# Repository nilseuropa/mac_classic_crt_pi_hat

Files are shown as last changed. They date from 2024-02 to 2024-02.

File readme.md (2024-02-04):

## Classic Mac CRT driver HAT for Raspberry Pi4

:warning: **Proof of concept running PoP on minivmac:**
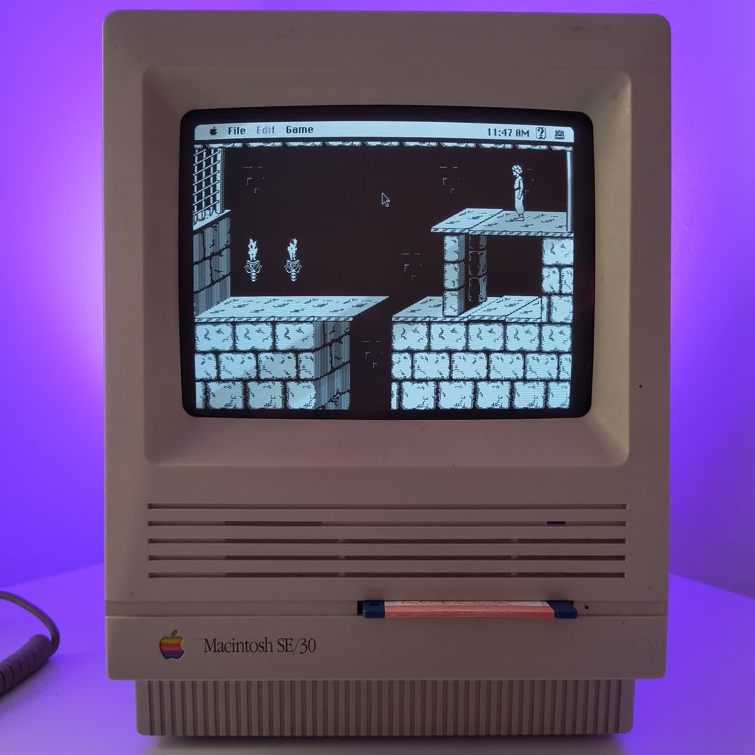
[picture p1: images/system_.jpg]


This method is utilizing the Display Parallel Interface of the RPi. The DPI device tree overlay has to be configured correctly to make this work. *(For fine tuning, troubleshooting or more detailed explanation please follow the link in the credits section to **nerdhut**'s original article.)* :arrow_left: KUDOS

### Configuration
```
dtoverlay=dpi24
overscan_left=0
overscan_right=0
overscan_top=0
overscan_bottom=0
framebuffer_width=512
framebuffer_height=342
enable_dpi_lcd=1
display_default_lcd=1
dpi_group=2
dpi_mode=87
dpi_output_format=0x76017
dpi_timings=512 0 14 178 0 342 0 0 4 24 0 0 0 60 0 15667200 1
```

### Schematics
Theoretically you can invert the data signal by just configuring the video hardware, but instead of that I have decided to sum the highest bits of the green, blue and red channels through an inverter IC. *( It could have been just 3 transistors. )*
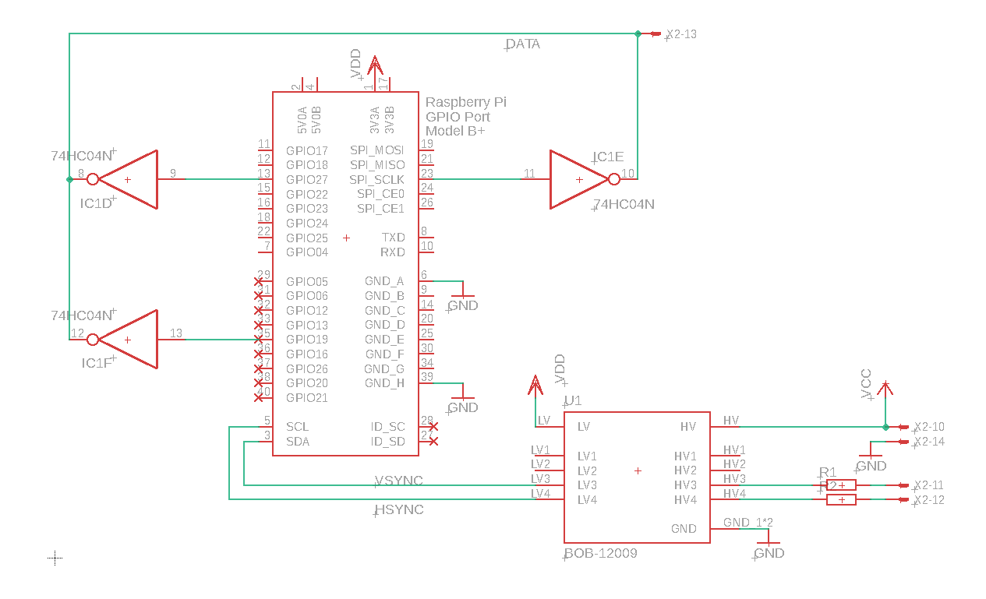
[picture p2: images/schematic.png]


### Board layout
The board has been quickly put together as an afternoon project. The goal was to quickly make a single sided prototype version based on DIP components. Feel free to edit the eagle source files included in this repository to your needs.

#### Top side
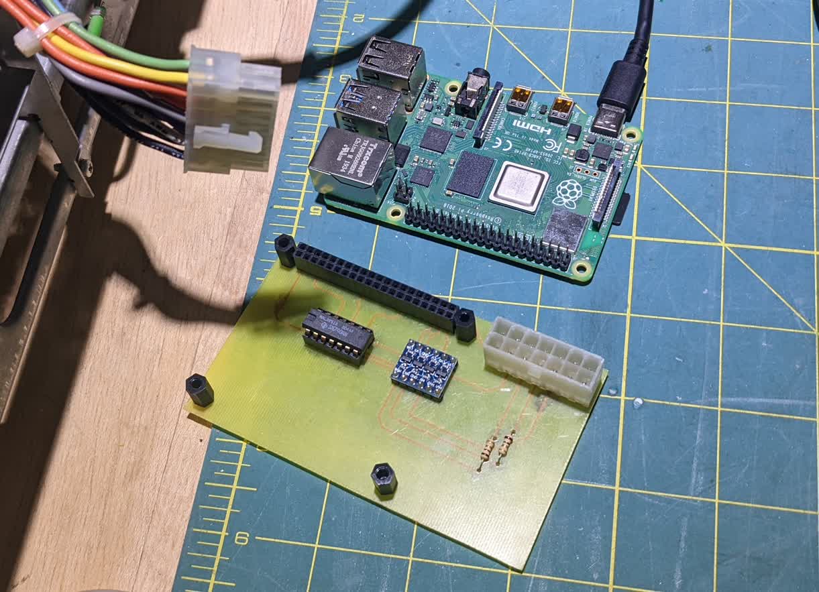
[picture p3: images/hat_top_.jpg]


#### Bottom side
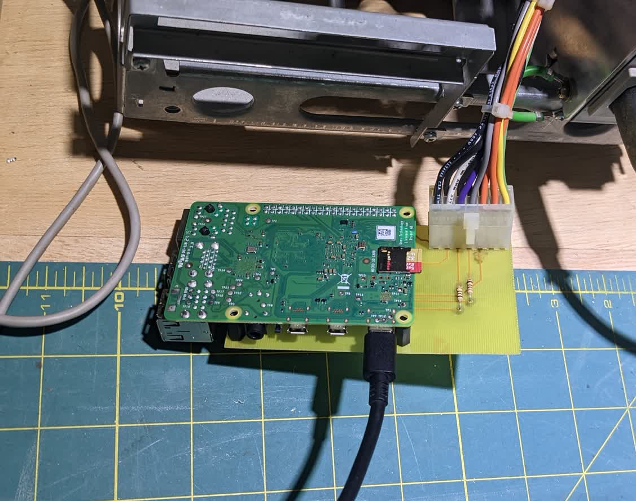
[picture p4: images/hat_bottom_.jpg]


### Build
As this was a quick and dirty build, I have just mounted the RPi with it's connectors facing outwards to a depron plate, held by a piece of aluminium angle that was lying around. This way I have access to the ethernet and USB ports.
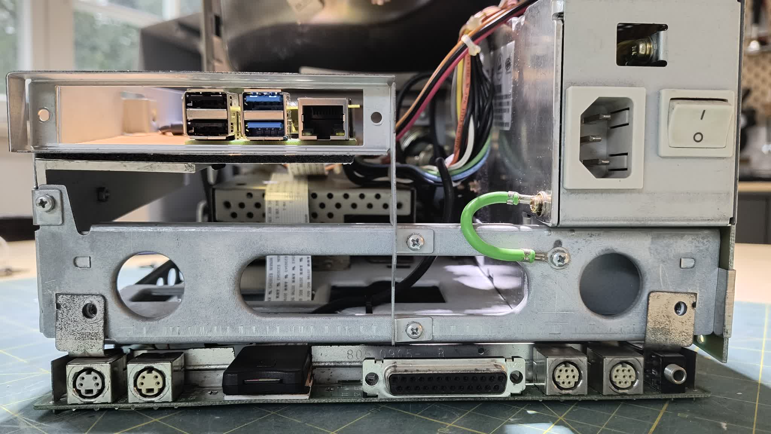
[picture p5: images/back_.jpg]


 I used a cheap SD Card extension cable, so that I can fiddle with the card without disassembling the whole contraption. *( I have reused the DSUB connector in my Apple // --- nothing goes to waste here ... :smile: )*
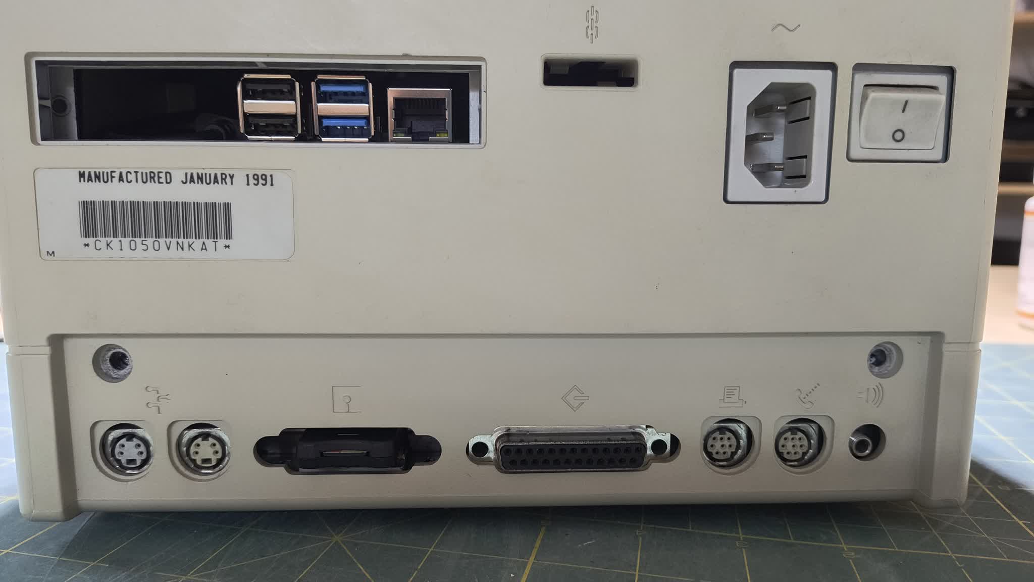
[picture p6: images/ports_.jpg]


### Final result
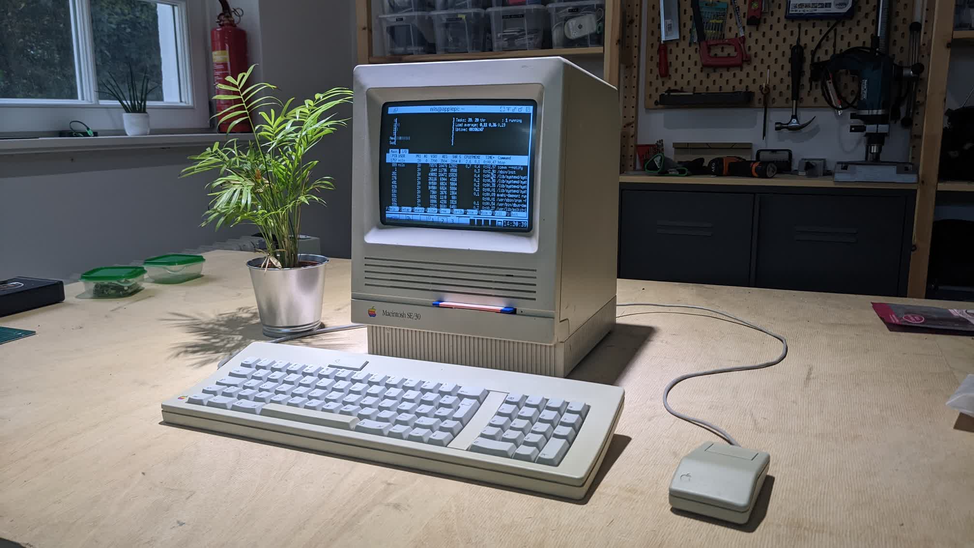
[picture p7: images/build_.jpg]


### Further plans *( big ideas, don't get any )*
* Currently the ADB connectors are hooked up through a microcontroller, that is totally unnecessary, the interface could go straight to the HAT instead.
* An additional SPI USB controller chip could be added to the HAT, supporting USB-SCSI.
* It would be nice to interface the floppy drive *( maybe through an integrated greaseweazle )*
* Another idea is to add an analog amplifier as well, so that the internal speaker is driven directly by the SBC. ( ... and the audio jacks )
* The whole thing could go in place of the original motherboard, with the connector interface matching the holes on the enclosure.

### Credits
Most credits go to **nerdhut** for doing all the heavy lifting. A truly elegant solution. :clap:
https://nerdhut.de/2020/03/17/raspberry-pi-dpi-control-crt/

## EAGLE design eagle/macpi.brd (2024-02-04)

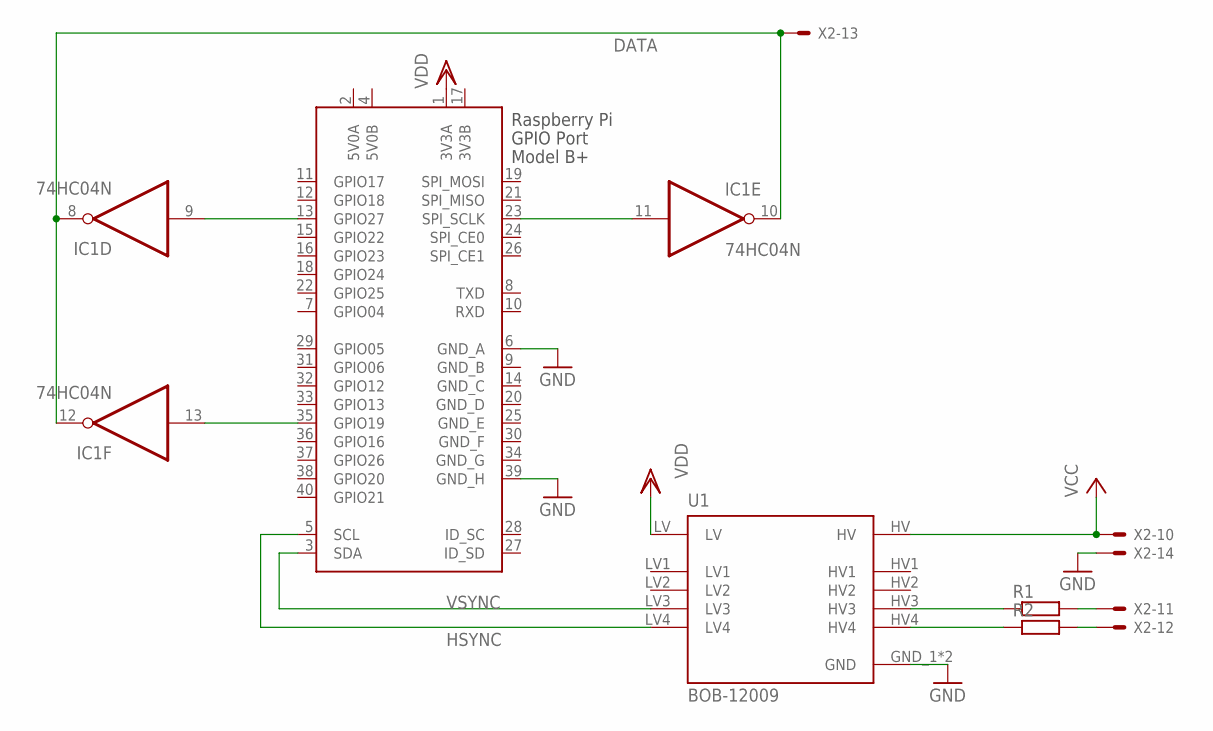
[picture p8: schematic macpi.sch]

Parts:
IC1: 74HC04N; DIL14
R1, R2: R-EU_VMTA55; VMTA55
U1: BOB-12009; CONV_BOB-12009
X1: RASPI_GPIO_B+#_PIN; RASPI_GPIO_B+_PIN
X2: 5566-14

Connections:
3V3B: X1.17 (3V3B)
5V0A: X1.2 (5V0A)
5V0B: X1.4 (5V0B)
DATA: IC1.8 (O), IC1.10 (O), IC1.12 (O), X2.13
GND: IC1.7 (GND), U1.GND_1 (GND), U1.GND_2 (GND), X1.6 (GND_A), X1.39 (GND_H), X2.14
GND_B: X1.9 (GND_B)
GND_C: X1.14 (GND_C)
GND_D: X1.20 (GND_D)
GND_E: X1.25 (GND_E)
GND_F: X1.30 (GND_F)
GND_G: X1.34 (GND_G)
HSYNC: U1.LV4, X1.5 (SCL)
unnamed: IC1.11 (I), X1.23 (SPI_SCLK)
unnamed: IC1.9 (I), X1.13 (GPIO27)
unnamed: IC1.13 (I), X1.35 (GPIO19)
unnamed: R2.1, U1.HV4
unnamed: R1.2, X2.11
unnamed: R1.1, U1.HV3
unnamed: R2.2, X2.12
VCC: IC1.14 (VCC), U1.HV, X2.10
VDD: U1.LV, X1.1 (3V3A)
VSYNC: U1.LV3, X1.3 (SDA)

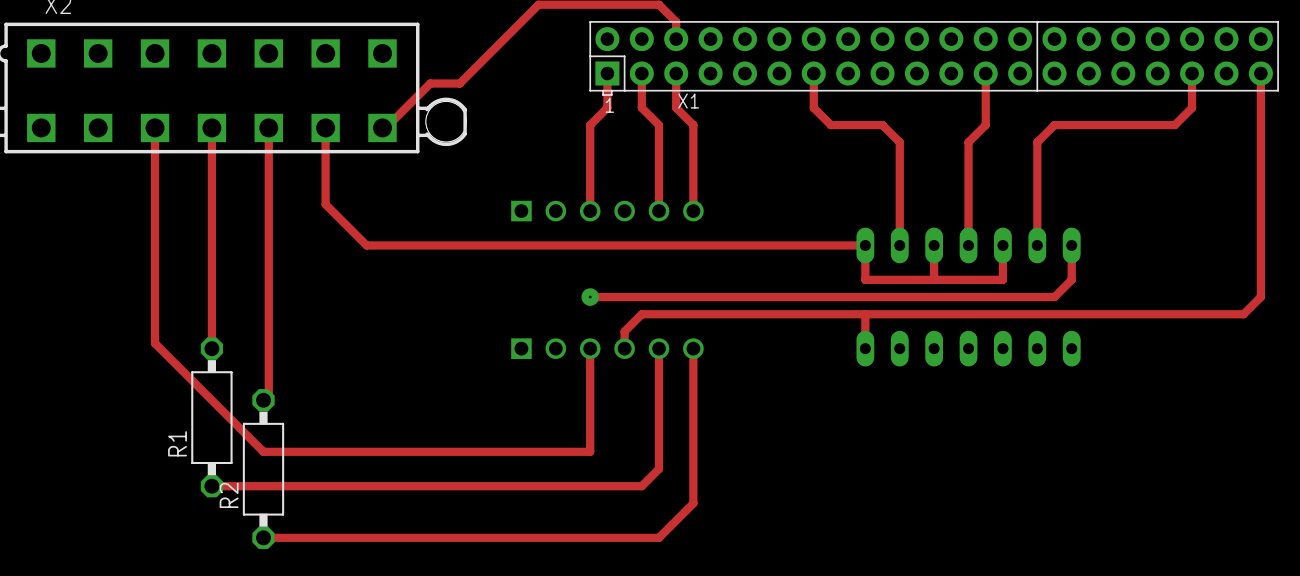
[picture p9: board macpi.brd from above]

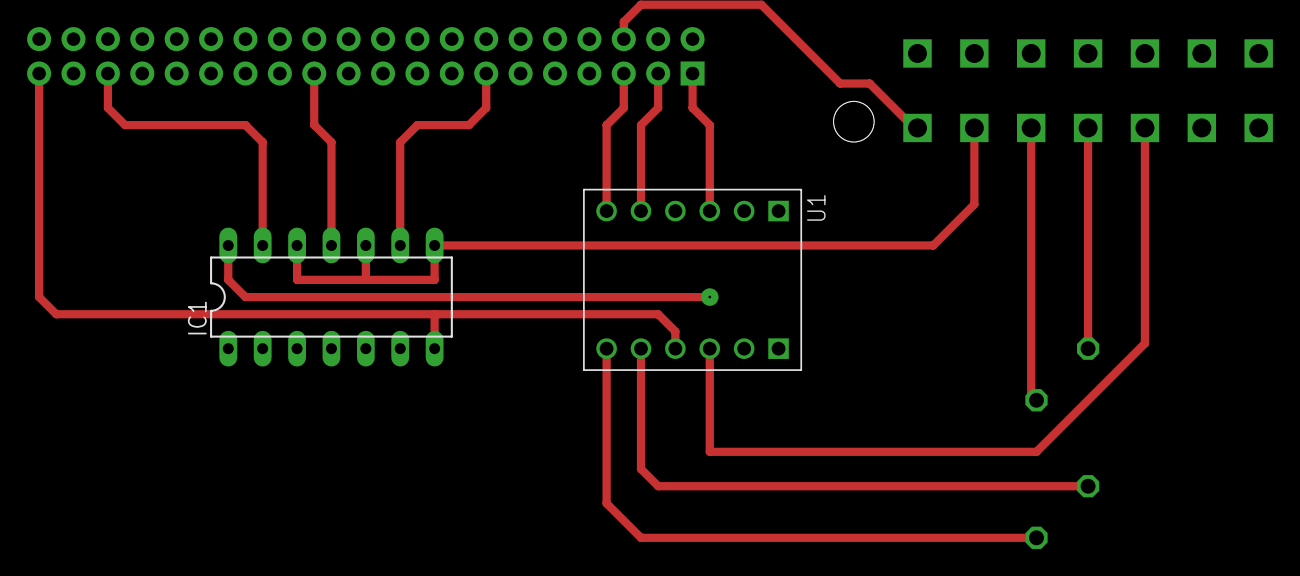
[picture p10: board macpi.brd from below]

Board: 2 copper layers, 6 parts (2 on the bottom side), 13 nets.
